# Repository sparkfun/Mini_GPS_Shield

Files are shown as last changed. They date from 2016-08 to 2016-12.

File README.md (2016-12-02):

SparkFun Mini GPS Shield
=============================================

SparkFun Mini GPS Shield

[*SparkFun Mini GPS Shield (GPS-14030)*](https://www.sparkfun.com/products/14030)

The [SparkFun Mini GPS Shield](https://www.sparkfun.com/products/14030) equips your Arduino with access to a GPS module, µSD memory card socket, and all of the other peripherals you'll need to turn your Arduino into a position-tracking, speed-monitoring, altitude-observing wonder logger. The shield is based around the [GP-735](https://www.sparkfun.com/products/13670) GPS Module -- a 56-channel GPS receiver featuring a uBlox 7th generation chipset and an up to 10Hz update rate.
 
 Repository Contents
-------------------
* **/Hardware** - All Eagle design files (.brd, .sch)

Documentation
-------------------
* [**Hookup Guide**](https://learn.sparkfun.com/tutorials/wireless-joystick-hookup-guide)

License Information
-------------------
The hardware is released under [Creative Commons ShareAlike 4.0 International](https://creativecommons.org/licenses/by-sa/4.0/).
The code is beerware; if you see me (or any other SparkFun employee) at the local, and you've found our code helpful, please buy us a round!

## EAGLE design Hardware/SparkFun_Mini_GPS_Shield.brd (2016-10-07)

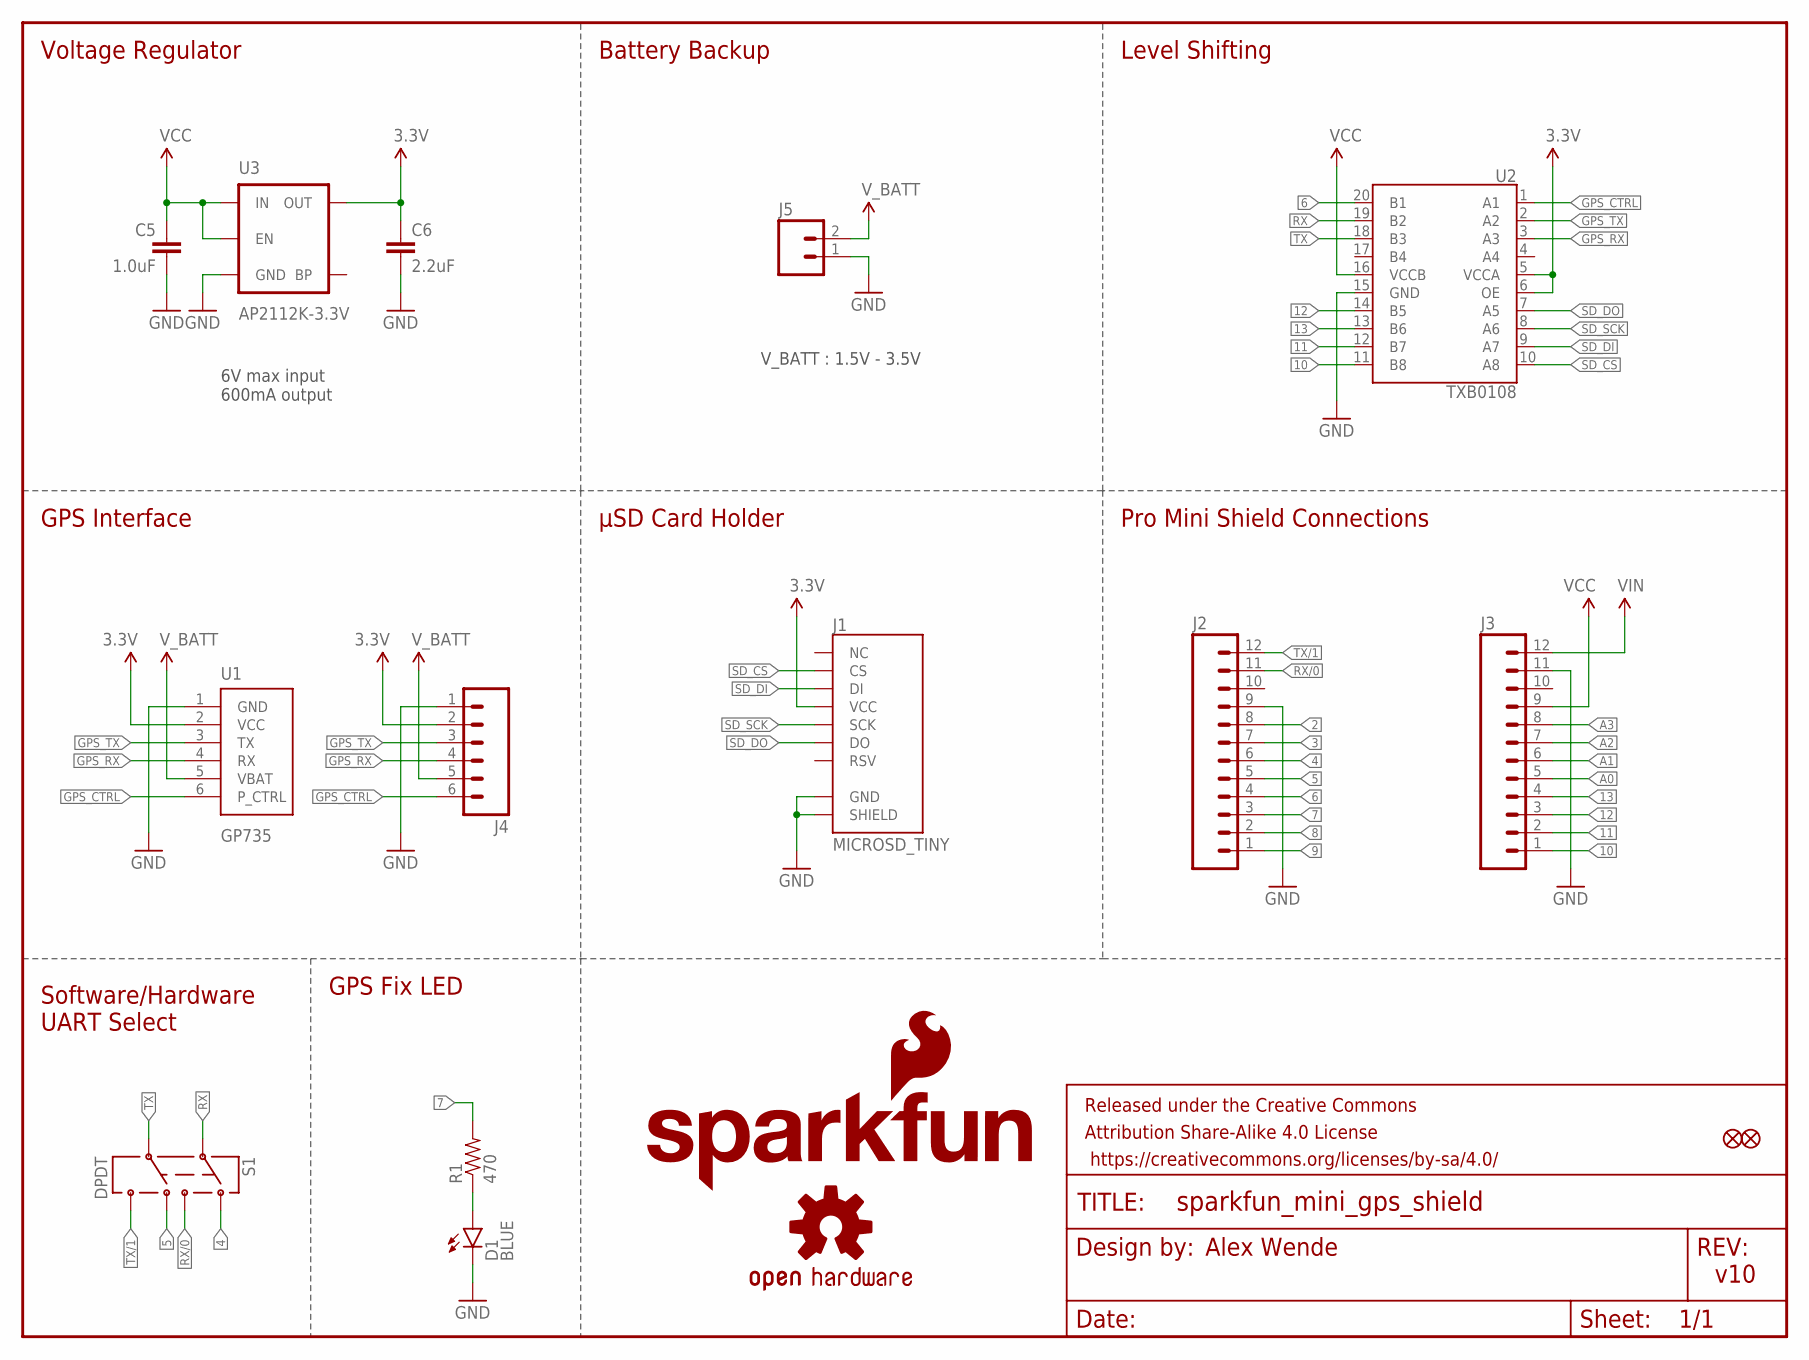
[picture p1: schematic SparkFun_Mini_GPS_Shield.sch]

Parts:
C5: 1.0uF; 0805-CAP
C6: 2.2uF; 0603-CAP
D1: BLUE; LED-0603
FD1, FD2: FIDUCIALUFIDUCIAL; MICRO-FIDUCIAL
FRAME1: FRAME-LETTER; CREATIVE_COMMONS
J1: MICROSD_TINY
J2, J3: M12NO_SILK; 1X12_NO_SILK
J4: M06NO_SILK_FEMALE_PTH; 1X06_NO_SILK
J5: M021X02_NO_SILK; 1X02_NO_SILK
LOGO1: OSHW-LOGOS; OSHW-LOGO-S
LOGO3: SFE_LOGO_FLAME.1_INCH; SFE_LOGO_FLAME_.1
LOGO4: SFE_LOGO_NAME.1_INCH; SFE_LOGO_NAME_.1
R1: 470; 0603-RES
S1: DPDT; AYZ0202
U1: GP735
U2: TXB0108; UFDFN-20
U3: AP2112K-3.3V; SOT23-5

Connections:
2: J2.8
3: J2.7
3.3V: C6.1, J1.4 (VCC), J4.2, U1.2 (VCC), U2.5 (VCCA), U2.6 (OE), U3.5 (OUT)
4: J2.6, S1.1
5: J2.5, S1.4
6: J2.4, U2.20 (B1)
7: J2.3, R1.2
8: J2.2
9: J2.1
10: J3.1, U2.11 (B8)
11: J3.2, U2.12 (B7)
12: J3.3, U2.14 (B5)
13: J3.4, U2.13 (B6)
A0: J3.5
A1: J3.6
A2: J3.7
A3: J3.8
GND: C5.2, C6.2, D1.C, J1.6 (GND), J1.GND1 (SHIELD), J1.GND2 (SHIELD), J1.GND3 (SHIELD), J1.GND4 (SHIELD), J1.GND5 (SHIELD), J1.GND6 (SHIELD), J2.9, J3.11, J4.1, J5.1, U1.1 (GND), U2.15 (GND), U3.2 (GND)
GPS_CTRL: J4.6, U1.6 (P_CTRL), U2.1 (A1)
GPS_RX: J4.4, U1.4 (RX), U2.3 (A3)
GPS_TX: J4.3, U1.3 (TX), U2.2 (A2)
unnamed: D1.A, R1.1
RX: S1.2, U2.19 (B2)
RX/0: J2.11, S1.3
SD_CS: J1.2 (CS), U2.10 (A8)
SD_DI: J1.3 (DI), U2.9 (A7)
SD_DO: J1.7 (DO), U2.7 (A5)
SD_SCK: J1.5 (SCK), U2.8 (A6)
TX: S1.5, U2.18 (B3)
TX/1: J2.12, S1.6
VCC: C5.1, J3.9, U2.16 (VCCB), U3.1 (IN), U3.3 (EN)
VIN: J3.12
V_BATT: J4.5, J5.2, U1.5 (VBAT)

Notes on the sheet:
6V max input 600mA output
Voltage Regulator
Battery Backup
Level Shifting
GPS Interface
Pro Mini Shield Connections
μSD Card Holder
Software/Hardware UART Select
GPS Fix LED
Alex Wende
v10
V_BATT : 1.5V - 3.5V

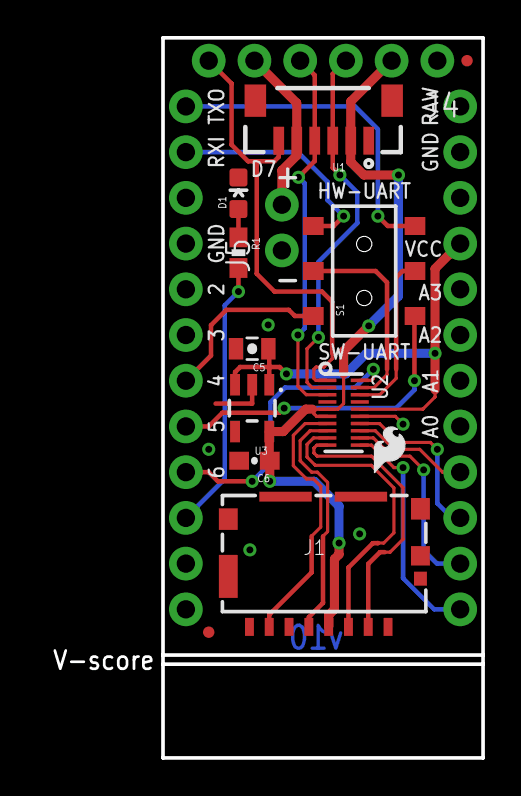
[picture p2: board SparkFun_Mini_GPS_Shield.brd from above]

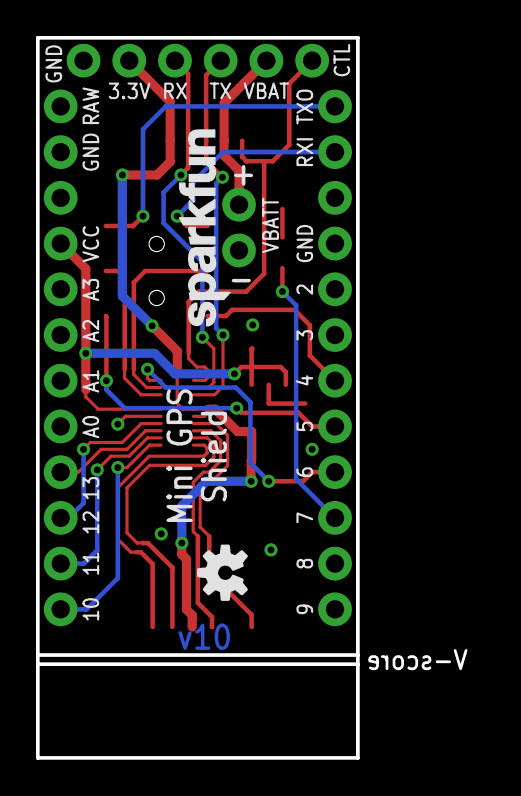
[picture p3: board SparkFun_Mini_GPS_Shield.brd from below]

Board: 2 copper layers, 17.8 x 40.0 mm, 19 parts (2 on the bottom side), 24 nets.

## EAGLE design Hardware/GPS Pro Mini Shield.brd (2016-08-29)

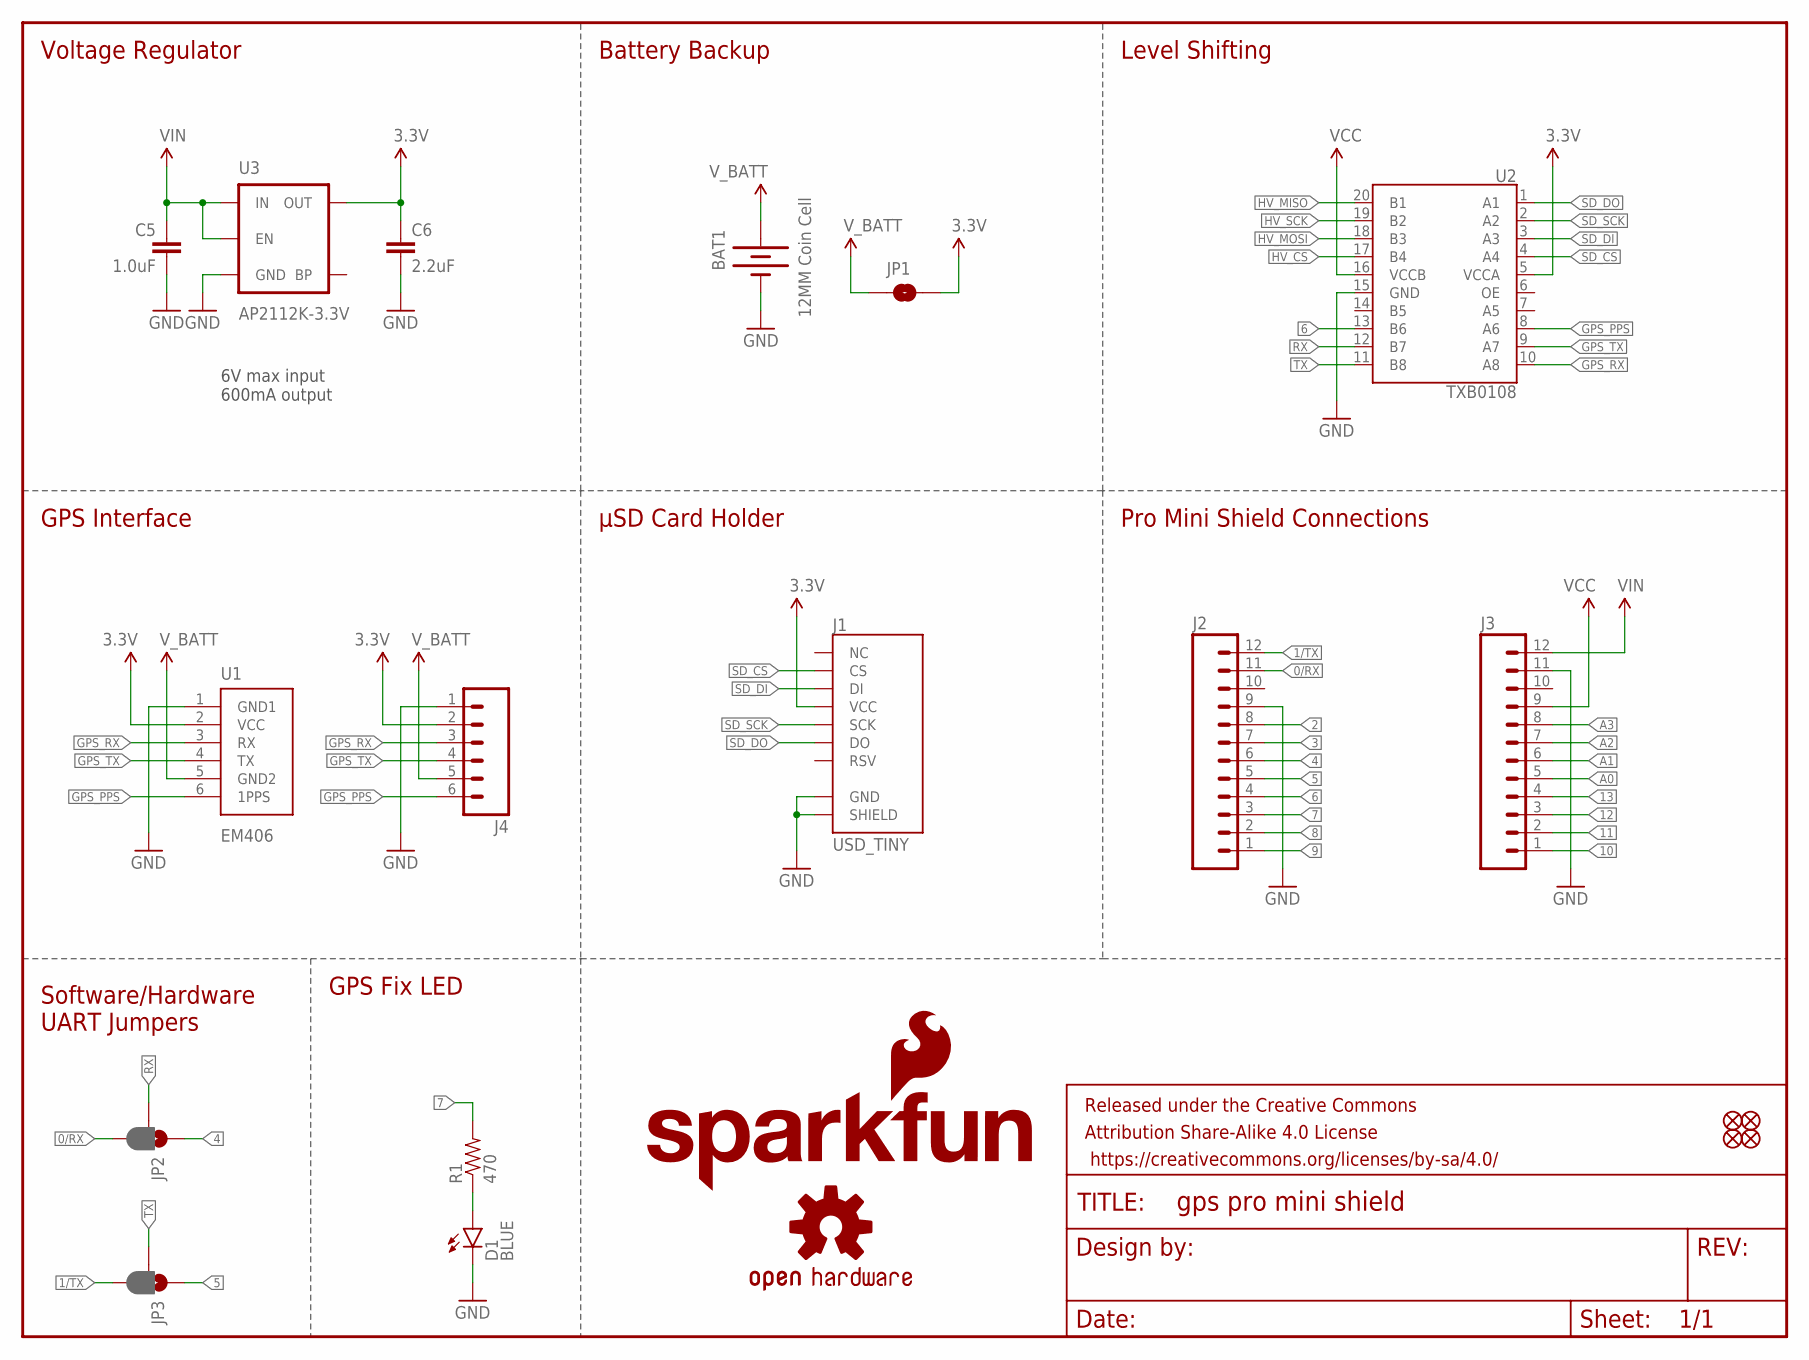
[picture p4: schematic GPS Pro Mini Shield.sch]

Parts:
BAT1: 12MM Coin Cell; BATTCON_12MM
C5: 1.0uF; 0805-CAP
C6: 2.2uF; 0603-CAP
D1: BLUE; LED-0603
FD1, FD2, FD3, FD4: FIDUCIALUFIDUCIAL; MICRO-FIDUCIAL
FRAME1: FRAME-LETTER; CREATIVE_COMMONS
J1: USD_TINY; SLIM_USD
J2, J3: M12NO_SILK; 1X12_NO_SILK
J4: M06NO_SILK_FEMALE_PTH; 1X06_NO_SILK
JP1: JUMPER-PAD-2-NOYES_SILK; PAD-JUMPER-2-NO_YES_SILK
JP2, JP3: JUMPER-PAD-3-2OF3_NC_BY_PASTE; PAD-JUMPER-3-2OF3_NC_BY_PASTE_YES_SILK_FULL_BOX
LOGO1: OSHW-LOGOS; OSHW-LOGO-S
LOGO3: SFE_LOGO_FLAME.1_INCH; SFE_LOGO_FLAME_.1
LOGO4: SFE_LOGO_NAME.1_INCH; SFE_LOGO_NAME_.1
R1: 470; 0603-RES
U1: EM406
U2: TXB0108; UFDFN-20
U3: AP2112K-3.3V; SOT23-5

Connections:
0/RX: J2.11, JP2.3
1/TX: J2.12, JP3.3
2: J2.8
3: J2.7
3.3V: C6.1, J1.4 (VCC), J4.2, JP1.2, U1.2 (VCC), U2.5 (VCCA), U3.5 (OUT)
4: J2.6, JP2.1
5: J2.5, JP3.1
6: J2.4, U2.13 (B6)
7: J2.3, R1.2
8: J2.2
9: J2.1
10: J3.1
11: J3.2
12: J3.3
13: J3.4
A0: J3.5
A1: J3.6
A2: J3.7
A3: J3.8
GND: BAT1.GND (-), C5.2, C6.2, D1.C, J1.6 (GND), J1.GND1 (SHIELD), J1.GND2 (SHIELD), J1.GND3 (SHIELD), J1.GND4 (SHIELD), J1.GND5 (SHIELD), J1.GND6 (SHIELD), J2.9, J3.11, J4.1, U1.1 (GND1), U2.15 (GND), U3.2 (GND)
GPS_PPS: J4.6, U1.6 (1PPS), U2.8 (A6)
GPS_RX: J4.3, U1.3 (RX), U2.10 (A8)
GPS_TX: J4.4, U1.4 (TX), U2.9 (A7)
HV_CS: U2.17 (B4)
HV_MISO: U2.20 (B1)
HV_MOSI: U2.18 (B3)
HV_SCK: U2.19 (B2)
unnamed: D1.A, R1.1
RX: JP2.2, U2.12 (B7)
SD_CS: J1.2 (CS), U2.4 (A4)
SD_DI: J1.3 (DI), U2.3 (A3)
SD_DO: J1.7 (DO), U2.1 (A1)
SD_SCK: J1.5 (SCK), U2.2 (A2)
TX: JP3.2, U2.11 (B8)
VCC: J3.9, U2.16 (VCCB)
VIN: C5.1, J3.12, U3.1 (IN), U3.3 (EN)
V_BATT: BAT1.PWR@1 (+), J4.5, JP1.1, U1.5 (GND2)

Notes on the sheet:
6V max input 600mA output
Voltage Regulator
Battery Backup
Level Shifting
GPS Interface
Pro Mini Shield Connections
μSD Card Holder
Software/Hardware UART Jumpers
GPS Fix LED

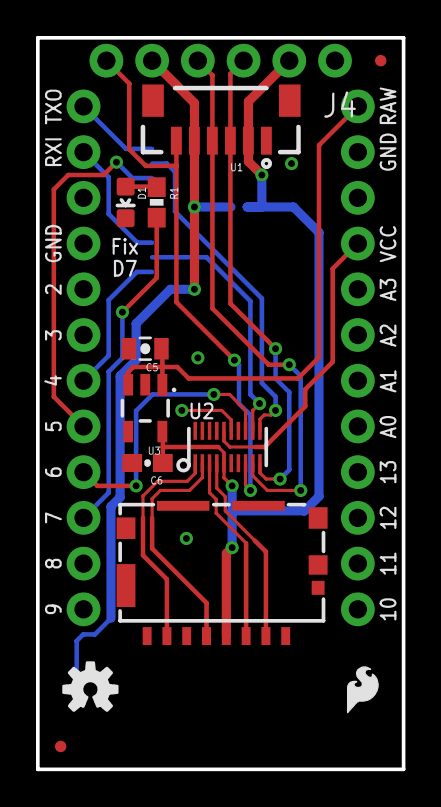
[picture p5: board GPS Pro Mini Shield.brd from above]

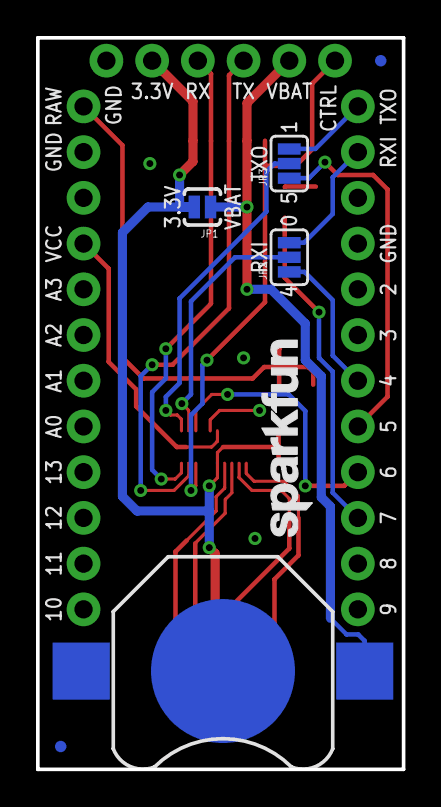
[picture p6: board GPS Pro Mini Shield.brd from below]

Board: 2 copper layers, 20.3 x 40.6 mm, 23 parts (7 on the bottom side), 21 nets.

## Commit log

2016-08-29 Initial Commit
    Added Eagle files and uSD card holder library
    [GPS Pro Mini Shield.brd, GPS Pro Mini Shield.sch]
2016-08-30 Update file names and library
    - Updated file names to follow standard
    - Updated library with PROD_ID numbers
    [SparkFun_GPS_Pro_Mini_Shield.brd, SparkFun_GPS_Pro_Mini_Shield.sch]
2016-08-30 Updated GPS label
    Changed from GPS_PPS to GPS_CTRL
    [SparkFun_GPS_Pro_Mini_Shield.brd, SparkFun_GPS_Pro_Mini_Shield.sch]
2016-08-30 Added board designer name and version number
    [SparkFun_GPS_Pro_Mini_Shield.brd, SparkFun_GPS_Pro_Mini_Shield.sch]
2016-09-01 Design Review Changes
    - Fixed SPI traces
    - Moved VIN of regulator to VIN instead of RAW
    - Removed jumpers for software/hardware uart with DPDT switch
    - Added product name to board
    - Replaced coin cell battery with two PTH pins to make the board smaller
    [SparkFun_GPS_Pro_Mini_Shield.brd, SparkFun_GPS_Pro_Mini_Shield.sch]
2016-09-06 QC Changes
    - shorted output enable to VCCA
    - added note of PCB thickness to tDocu
    - added VBATT to bottom silk for 2-pin vbatt header
    [SparkFun_GPS_Pro_Mini_Shield.brd, SparkFun_GPS_Pro_Mini_Shield.sch]
2016-09-06 QC changes
    -shorted output enable to VCCA
    - added note about PCB thickness
    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
    [SparkFun_GPS_Pro_Mini_Shield.brd]
2016-09-06 Minor changes
    [SparkFun_GPS_Pro_Mini_Shield.brd]
2016-10-05 V10 Changes
    - Changed board name to "Mini GPS Shield".
    - Extended board length to better support uSD card.
    - Added v-score to board extention
    - Changed control pin name to "CTL" instead of "CTR"
    [SparkFun_Mini_GPS_Shield.brd, SparkFun_Mini_GPS_Shield.sch]
2016-10-05 Moved v-score label
    - Moved v-score label to dimention layer instead of tDocu
    [SparkFun_Mini_GPS_Shield.brd]
2016-10-07 Changed UART net labels
    0/RX and 1/TX are now RX/0 and TX/1
    [SparkFun_Mini_GPS_Shield.brd, SparkFun_Mini_GPS_Shield.sch]

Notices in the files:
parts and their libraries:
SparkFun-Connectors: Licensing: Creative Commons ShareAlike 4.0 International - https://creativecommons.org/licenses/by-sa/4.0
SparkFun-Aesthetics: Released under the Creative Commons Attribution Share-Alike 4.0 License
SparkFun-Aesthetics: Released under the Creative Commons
